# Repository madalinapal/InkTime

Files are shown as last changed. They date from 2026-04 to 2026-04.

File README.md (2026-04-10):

# InkTime Smartwatch

## Overview
InkTime Watch is a low-power smartwatch based on the nRF52840 microcontroller, designed for efficient timekeeping, motion tracking, and e-paper display usage.

## Hardware diagram & features
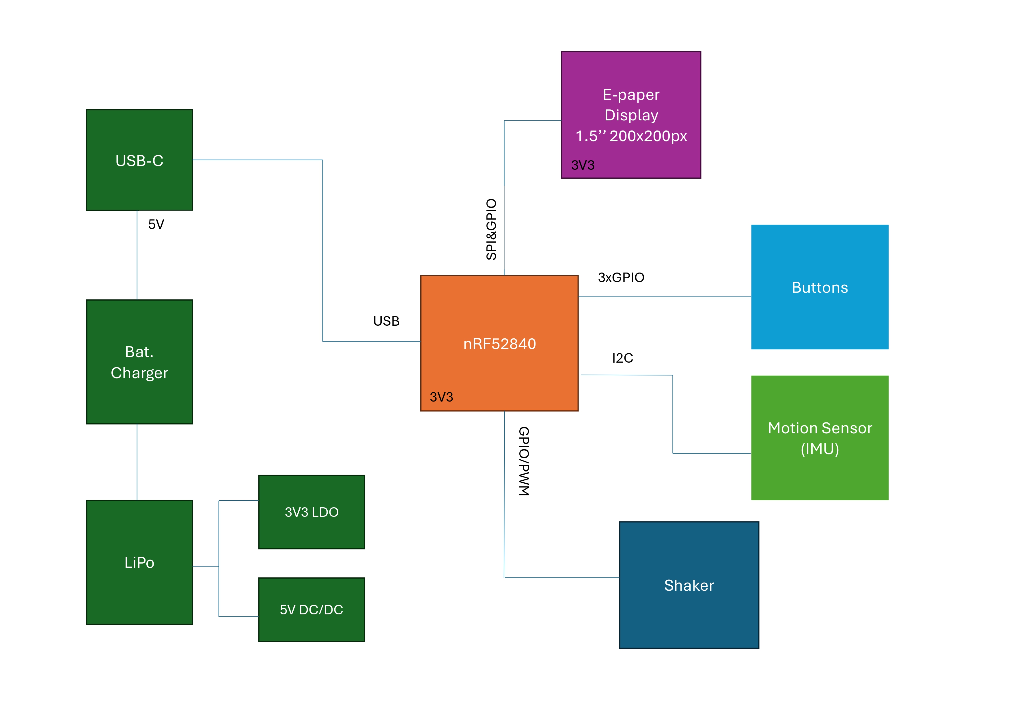
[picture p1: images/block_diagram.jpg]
Block diagram


This is an open-hardware wearable based on the nRF52840 microcontroller. It is fully compatible with embedded C/C++ development and comes with the following features:

* [nRF52840](https://files.seeedstudio.com/wiki/XIAO-BLE/Nano_BLE_MCU-nRF52840_PS_v1.1.pdf) microcontroller (ARM Cortex-M4F @ 64 MHz, Bluetooth 5 / BLE, 2.4 GHz radio, 1 MB Flash and 256 KB RAM, multiple interfaces: SPI, I2C, UART, GPIO, support for external antenna)
* [E-paper Display](https://www.waveshare.com/1.54inch-e-paper-module.htm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) 1.54 inch, 200x200 resolution, communicating via SPI interface
* [BMA423](https://watchy.sqfmi.com/assets/files/BST-BMA423-DS000-1509600-950150f51058597a6234dd3eaafbb1f0.pdf) accelerometer (3-axis ultra-low-power MEMS accelerometer, integrated step counting and activity recognition, motion detection interrupts, FIFO buffer, I2C/SPI interface, optimized for wearable low-power applications)
* [BQ25180](https://www.ti.com/product/BQ25180) LiPo Charger (I2C-controlled single-cell Li-Ion/Li-Po charger, 5V USB input, up to ~250 mA charging current, integrated power path management, ultra-low power for wearables)
* [250 mAh LiPo battery](https://elektronik.ropla.eu/pdf/stock/aky/aky1119.pdf)
* [FIT0774](https://www.tme.eu/ro/details/df-fit0774/motoare-dc/dfrobot/fit0774/) vibration motor (small DC vibration motor, 10 mm diameter, 2.7 mm height, 1.5–4.2 V operating voltage, used for haptic feedback in wearable devices)
* [TC2030-IDC](https://www.digikey.ro/ro/products/detail/tag-connect-llc/TC2030-IDC/4571121) debug connector (Tag-Connect 10-pin SWD programming interface, no-socket pogo-pin connector, supports SWDIO, SWDCLK, RESET, VCC and GND, used for low-profile in-circuit debugging of MCUs)
* [DRV2605L](https://www.ti.com/product/DRV2605L) haptic driver (I2C-controlled vibration motor driver with integrated haptic library, supports ERM and LRA actuators, automatic resonance tuning, low-power operation for wearable haptic feedback systems)
* [DS6160A](https://www.mouser.com/datasheet/2/1458/DS6160A_02-3104604.pdf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) regulator (dual-channel low-power audio power amplifier / driver IC, designed for small speaker or actuator applications, wide supply voltage range, high efficiency Class-D operation, suitable for compact battery-powered systems)
* [MAX17048](https://www.analog.com/en/products/max17048.html) fuel gauge (ultra-low-power single-cell Li-ion battery fuel gauge IC, I2C interface, uses ModelGauge algorithm for accurate state-of-charge estimation, no external sense resistor required, optimized for wearable and portable devices)

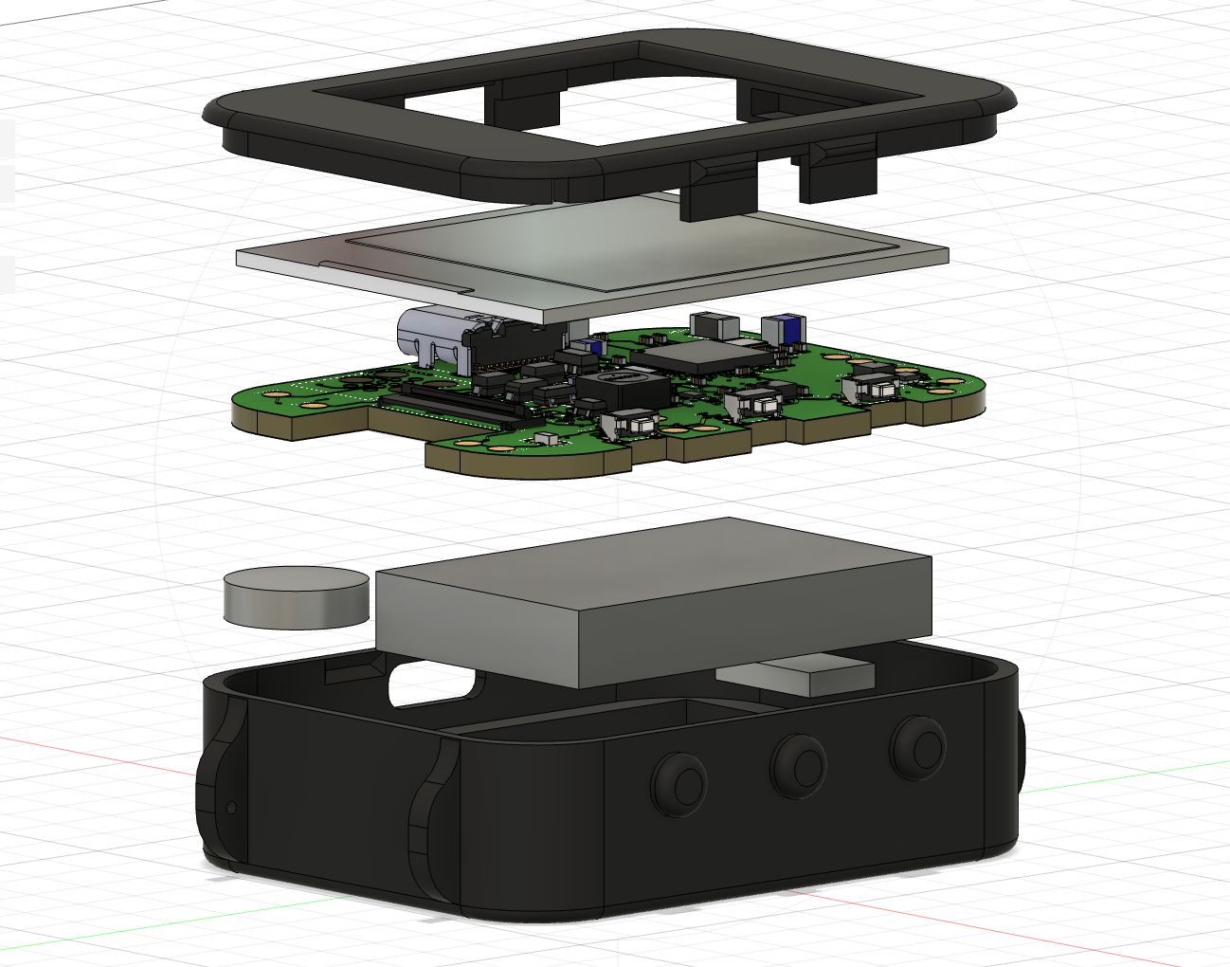
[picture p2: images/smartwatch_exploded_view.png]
Smartwatch exploded view


## Bill of Materials (BOM)

The table below summarizes the main components used in the project. Passive components are grouped by type and package to improve readability.

| Component | Description | Qty | Manufacturer | Part Number | Datasheet | 
|---|---|-----|---|---|---|
| nRF52840 | BLE Microcontroller | 1 | Nordic Semiconductor | nRF52840 | [Datasheet](https://files.seeedstudio.com/wiki/XIAO-BLE/Nano_BLE_MCU-nRF52840_PS_v1.1.pdf) | 
| BMA423 | 3-axis accelerometer (IMU) | 1 | Bosch | BMA423 | [Datasheet](https://watchy.sqfmi.com/assets/files/BST-BMA423-DS000-1509600-950150f51058597a6234dd3eaafbb1f0.pdf) |
| BQ25180 | Battery charger / PMIC | 1 | Texas Instruments | BQ25180 | [Datasheet](https://www.ti.com/product/BQ25180) |
| DRV2605L | Haptic driver | 1 | Texas Instruments | DRV2605L | [Datasheet](https://www.ti.com/product/DRV2605L) |
| MAX17048 | Fuel gauge | 1 | Analog Devices | MAX17048G+T10 | [Datasheet](https://www.analog.com/en/products/max17048.html) | 
| RT6160 | Buck-boost converter | 1 | Richtek | RT6160AWSC | [Datasheet](https://www.mouser.com/datasheet/2/1458/DS6160A_02-3104604.pdf) | 
| 2450AT18B100E | 2.4GHz chip antenna | 1 | Johanson Technology | 2450AT18B100E | [Datasheet](https://jlcpcb.com/api/file/downloadByFileSystemAccessId/8588940948130156544) |
| TC2030-IDC | Programming connector | 1 | Tag-Connect | TC2030-IDC | [Datasheet](https://www.lcsc.com/datasheet/C5444772.pdf) | 
| USB-C Connector | Power & data interface | 1 | Kinghelm | KH-TYPE-C-16P | [Datasheet](https://jlcpcb.com/api/file/downloadByFileSystemAccessId/8588905154556923904) | 
| FPC Connector | E-paper display connector | 1 | Molex | 503480-2400 |[Datasheet](https://www.molex.com/content/dam/molex/molexdotcom/products/automated/enus/salesdrawingpdf/503/503480/5034802400_sd.pdf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)| 
| Push Buttons | Tactile switches | 3 | Panasonic | EVP-AKE31A | [Datasheet](https://wmsc.lcsc.com/wmsc/upload/file/pdf/v2/lcsc/2301111010_PANASONIC-EVPAKE31A_C569760.pdf) | 
| MOSFETs | Power switching | 2 | Vishay / Diodes Inc. | SI1308EDL / DMG2305UX | [Datasheet](https://www.lcsc.com/datasheet/C469327.pdf) | 
| Diodes | Schottky diodes | 3 | ON Semiconductor | MBR0530 | [Datasheet](https://www.lcsc.com/datasheet/C77336.pdf) | 
| ESD Protection | USB protection | 1 | STMicroelectronics | USBLC6-2SC6 | [Datasheet](https://www.lcsc.com/datasheet/C7519.pdf) | 
| Crystal | 32MHz | 1 | NDK | NX2016SA-32MHZ-EXS00A-CS11336 | [Datasheet](https://wmsc.lcsc.com/wmsc/upload/file/pdf/v2/lcsc/2312080231_NDK-NX2016SA-32MHZ-EXS00A-CS11336_C6134317.pdf) | 
| Crystals | 32.768kHz | 1 | Seiko Epson | FC-135 32.7680KA-A3 | [Datasheet](https://jlcpcb.com/partdetail/SeikoEpson-FC_135_32_7680KAA3/C2650472) | 

## nRF52840 Pin Mapping

| Pin nRF52840 | Signal | Component | Interface |
|---|---|---|---|
| P0.00/XL1 | XL1 | Crystal X2 (32.768kHz) | XTAL |
| P0.01/XL2 | XL2 | Crystal X2 (32.768kHz) | XTAL |
| P0.05/AIN3  | EPD_CS | E-Paper (J1 FPC) | SPI CS |
| P0.06 | SDA | BMA423, BQ25180, MAX17048, DRV2605 | I2C SDA |
| P0.07 | SCL | BMA423, BQ25180, MAX17048, DRV2605 | I2C SCL |
| P0.08 | IMU_INT1 | BMA423 | GPIO Input |
| P1.08 | IMU_INT2 | BMA423 | GPIO Input |
| P0.11 | PMIC_INT | BQ25180 | GPIO Input |
| P0.12 | HAPTIC_EN  | DRV2605 | GPIO |
| VBUS | VBUS | USB-C (J4) | Power |
| D- | D- | USB-C (J4) / USBLC6 | USB |
| D+ | D+ | USB-C (J4) / USBLC6 | USB |
| P0.13 | SW_UP | Buton Up | GPIO Input |
| P0.14 | SW_ENT | Buton Enter | GPIO Input |
| P0.15 | EPD_DC | E-Paper (J1 FPC) | SPI DC |
| P0.16 | EPD_RST | E-Paper (J1 FPC) | GPIO |
| P0.17 | EPD_BUSY | E-Paper (J1 FPC) | GPIO Input |
| P0.18/RESET | RESET | TC2030-IDC | SWD/GPIO |
| SWDCLK | SWDCLK | TC2030-IDC | SWD |
| SWDIO | SWDIO | TC2030-IDC | SWD |
| P1.02 | SW_DN | Buton Down | GPIO Input |
| P0.10/NFC2  | ALERT | MAX17048 | GPIO Input |
| ANT | RF | Antena 2450AT18B100E | RF |
| P0.02/AIN0  | SCK | E-Paper (J1 FPC) | SPI SCK |
| P0.03/AIN1  | MOSI | E-Paper (J1 FPC) | SPI MOSI |

## Design Log

This section describes the PCB design process, decisions taken during implementation, and how the project complies with the imposed design constraints.

---

###  Placement Strategy

The layout process started with the placement of mechanically constrained and critical components such as:
- USB-C connector
- Side buttons
- E-paper display connector (FPC)
- nRF52840 microcontroller

These components were positioned according to the mechanical enclosure to ensure proper alignment and usability.

All components were placed exclusively on the **TOP layer**, as required. Passive components (resistors, capacitors) were then distributed around their corresponding ICs, minimizing trace length and ensuring proper decoupling.

Special attention was given to **100nF decoupling capacitors**, which were placed as close as possible to the power pins of each integrated circuit.

---

###  Routing Strategy

Routing was performed on a **4-layer PCB stack-up**, structured as follows:
- Top Layer – signal routing and component placement
- Inner Layer 1 – solid ground plane (GND)
- Inner Layer 2 – power plane (VCC, 3V3, etc.)
- Bottom Layer – signal routing

The routing process followed a hierarchical approach:
- Power traces (VCC, VBUS, 3V3) were routed first
- Signal traces were routed afterwards

Design rules applied:
- Power traces: **≥ 0.3 mm width** 
- Signal traces: **≥ 0.15 mm width**
- No 90° angles were used (only smooth or 45° routing)

The use of internal planes significantly improved power distribution and return paths, reducing noise and ensuring signal integrity.

---

###  Grounding and Planes

A solid grounding strategy was implemented using **polygon pours** on ground layers.

- Ground planes were applied on multiple layers
- **Via stitching** was used extensively to connect ground planes
- Increased via density was applied near the RF section

This improves:
- Signal return paths
- Noise reduction
- EMI performance

---

###  RF and Antenna Considerations

The antenna area was treated as a strict keep-out zone:
- No copper
- No traces
- No vias

---

### Component Constraints

All components respect the required footprint rules:

- Resistors: **0201**
- Capacitors ≤100nF: **0201**
- Capacitors >100nF: **0402**
  
## Design Rule Exceptions (Accepted)

**Trace Width (accepted):**  
Power nets (3V3, VREG, VBAT, VBUS) follow the 0.3 mm rule, but in dense areas around the nRF52840 and tightly packed components, traces are locally reduced due to limited space. These segments are short and were accepted after verification.

**Copper Clearance (accepted):**  
The minimum clearance rule (0.15 mm) is slightly violated in congested regions, especially near the nRF52840 and 0201 components. All cases were manually checked to ensure no shorts.

**Board Edge Clearance (accepted):**  
The USB-C connector (J4) and buttons (SW_UP, SW_DN, SW_ENT) extend beyond the PCB edge for enclosure alignment. This is intentional.

This ensures high-density integration suit

## Repository contens
- schematic.sch → Schematic design file  
- board.brd → PCB layout file  

### Manufacturing
- GerberFiles.zip → PCB manufacturing files (Gerber + drill files)  
- bom.csv / bom.xlsx → Bill of Materials  
- pick&place.cpl → Component placement file 

### Mechanical
- smartwatch_exploded_view.stp → Full 3D exploded view (PCB + battery + display + enclosure)  
- smartwatch.stp → Full 3D view 

### Images
- pcb_2d.png 
- pcb_3d_top_view.png
- pcb_3d_bottom_view.png
- pcb_3d_side_view
- block_diagram.jpg
- smartwatch_final.png
- smartwatch_side_view1.png
- smartwatch_side_view2.png
- smartwatch_exploded_view.png

### License
- LICENSE → Open-source license file 

### Documentation
- README.md → Main project documentation

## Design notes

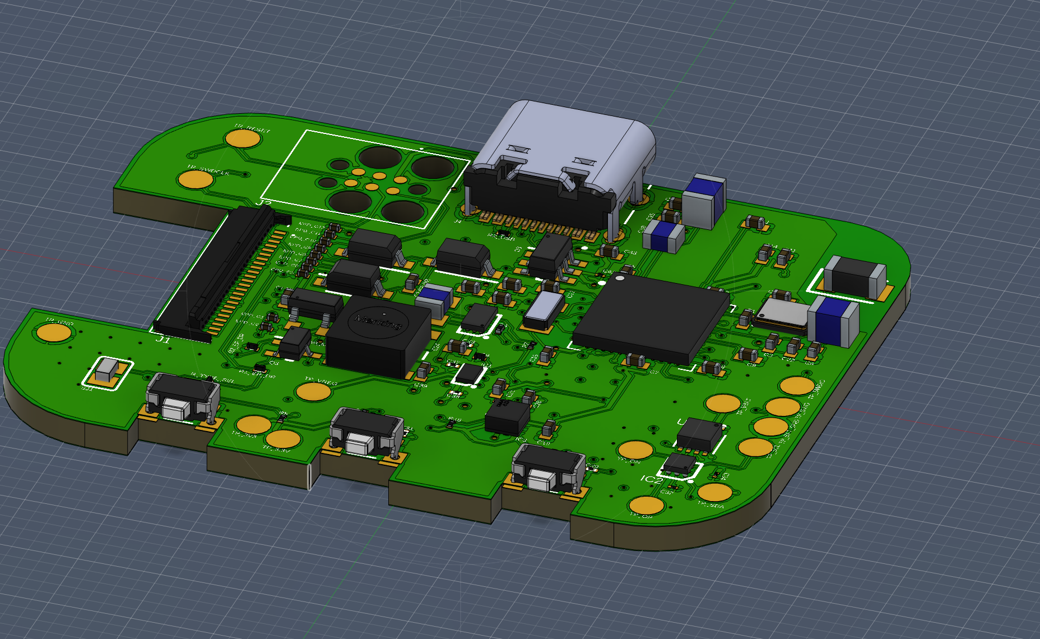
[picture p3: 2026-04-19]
images/pcb_3d_side_view.png

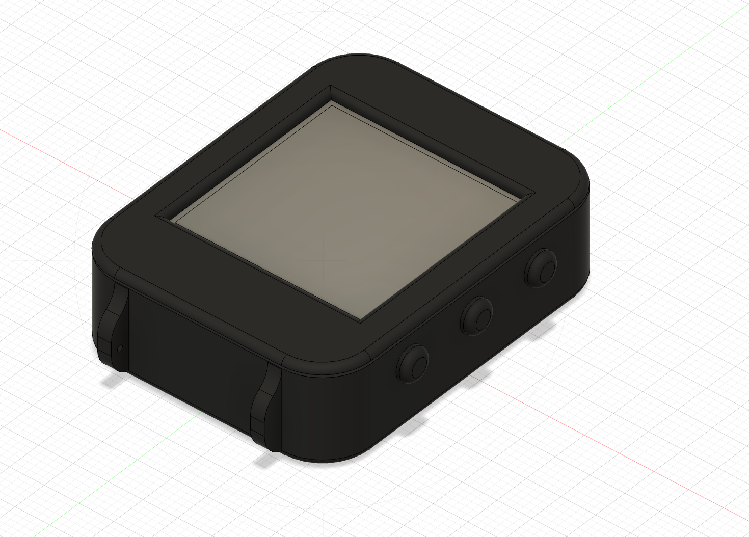
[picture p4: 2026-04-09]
images/smartwatch_final.png

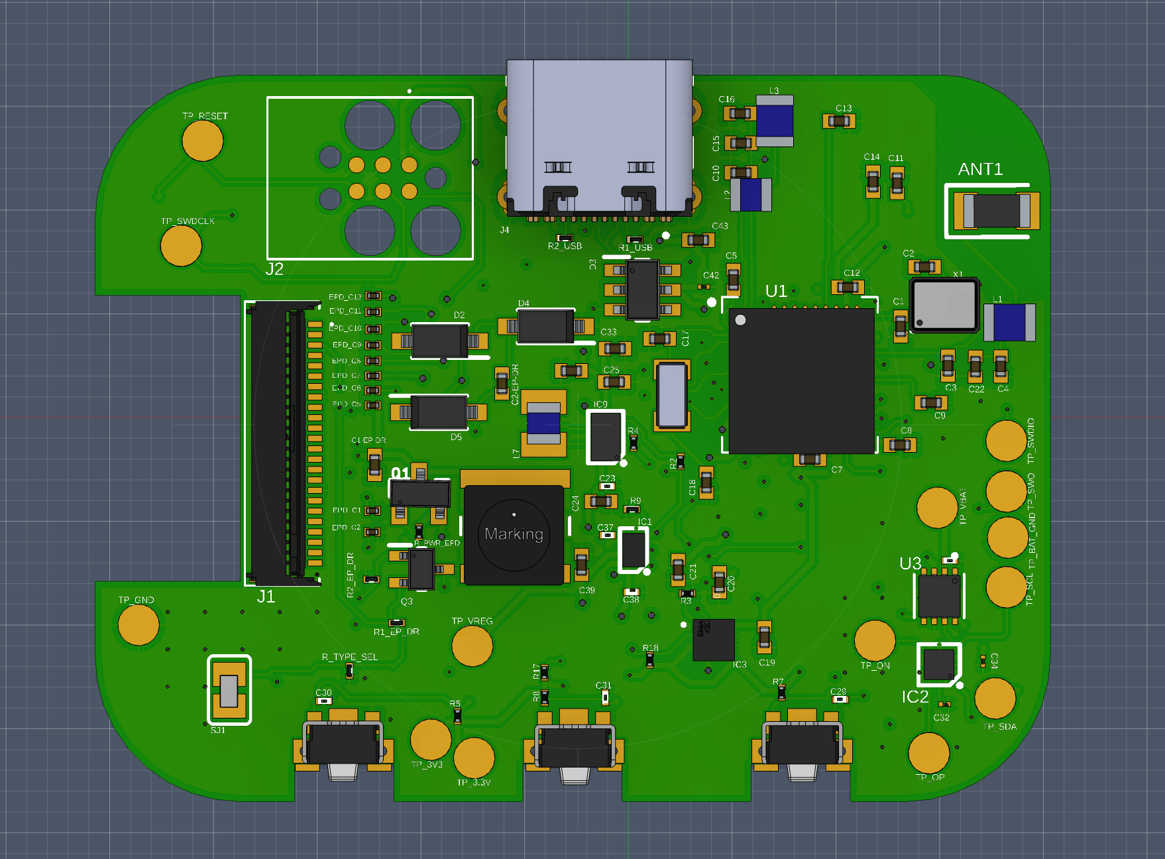
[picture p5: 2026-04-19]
images/pcb_3d_top_view.png

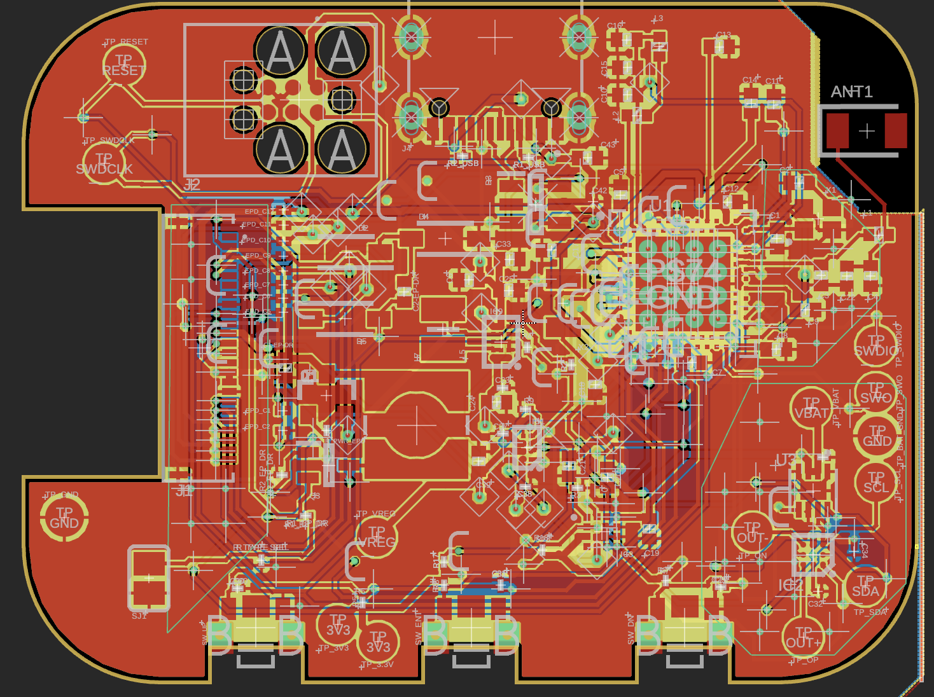
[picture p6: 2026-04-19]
images/pcb_2d.png

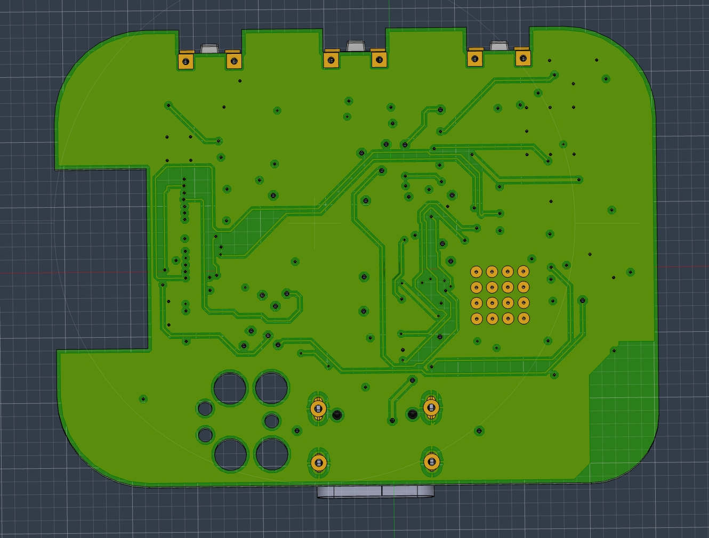
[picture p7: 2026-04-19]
images/pcb_3d_bottom_view.png

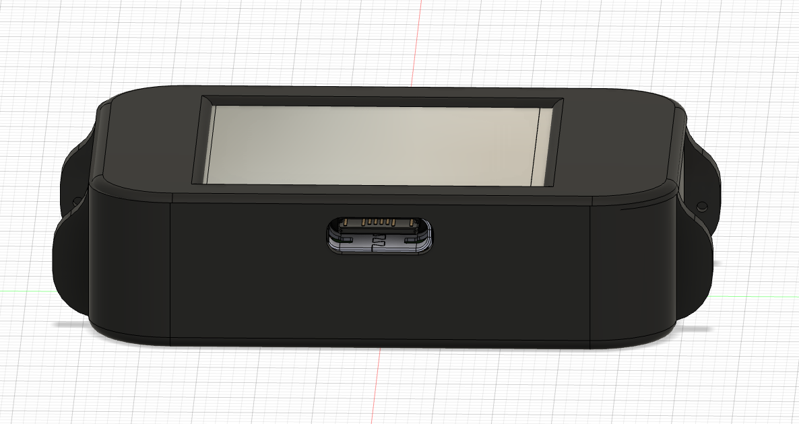
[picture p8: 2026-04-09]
images/smarwatch_side_view1.png

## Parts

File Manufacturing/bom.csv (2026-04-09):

Qty | Value | Device | Package | Parts | Description | ARROW_PART_NUMBER | ARROW_PRICE-STOCK | AVAILABILITY | CHECK_PRICES | COPYRIGHT | DESCRIPTION | DIGI-KEY_PART_NUMBER_1 | DIGI-KEY_PART_NUMBER_2 | DIGI-KEY_PART_NUMBER_3 | HEIGHT | JLCPCB | MANUFACTURER_NAME | MANUFACTURER_PART_NUMBER | MF | MFR_NAME | MOUSER_PART_NUMBER | MOUSER_PRICE-STOCK | MP | PACKAGE | POPULARITY | PRICE | PROD_ID | PURCHASE-URL | SNAPEDA_LINK | TP_SIGNAL_NAME | VALUE
1 |  | 2450AT18B100E_2450AT18B100E | 2450AT18B100E_ANTC3216X140N | ANT1 | Antennas 2.45GHz ANTENNA | 2450AT18B100E | https://www.arrow.com/en/products/2450at18b100e/johanson-dielectrics?utm_currency=USD&region=nac |  |  |  | Antennas 2.45GHz ANTENNA |  |  |  | 1.4mm |  | JOHANSON TECHNOLOGY | 2450AT18B100E |  |  | 609-2450AT18B100E | https://www.mouser.co.uk/ProductDetail/Johanson-Technology/2450AT18B100E?qs=yCnrNFeXz%252Bh5MFsFIXGZGA%3D%3D
1 |  | ESP32_C6_LIBRARY_7_JUMPER_SJ | ESP32_C6_LIBRARY_7_JUMPER_SJ | SJ1 | SMD solder JUMPER |  |  |  |  |  |  |  |  |  |  |  |  |  |  |  |  |  |  |  | 3
3 | 0 | ERA-1AEB3401C_CPF0201D7K68C1 | ERA-1AEB3401C_0201 | R2, R3, R4 | 7.68k 0201 Thin Film Surface Mount Fixed Resistor +/-0.5% 0.031W CPF0201D7K68C1
2 | 0.1uF | GRM011R60J152KE01L_1_GRM011R60J152KE01L | GRM011R60J152KE01L_1_0201 | C23, C27 | Check availability
2 | 0.1uF | GRM011R60J152KE01L_2_GRM011R60J152KE01L | GRM011R60J152KE01L_2_CAPC0201X13N | C34, C42 | Check availability |  |  | In Stock | https://www.snapeda.com/parts/GRM011R60J152KE01L/Murata/view-part/?ref=eda |  | SMD Capacitor X5R(EIA) with Capacitance: 1500pF Tol. 10%. Rated Voltage: 6.3Vdc |  |  |  |  |  |  |  | Murata |  |  |  | GRM011R60J152KE01L | 0201 Murata |  | None |  |  | https://www.snapeda.com/parts/GRM011R60J152KE01L/Murata/view-part/?ref=snap
1 | 0.1uF/50V | NORDIC_NRF_3_CAPACITOR_0201_L | NORDIC_NRF_3_RESC0201_L | EPD_C5 | Generic chip capacitor
1 | 0.47 | CPF0201D7K68C1_CPF0201D7K68C1 | CPF0201D7K68C1_0201 | R1_EP_DR | 7.68k 0201 Thin Film Surface Mount Fixed Resistor +/-0.5% 0.031W CPF0201D7K68C1
1 | 1.0uF | PERFECT_0402_CAP_0402 | PERFECT_0402_0402 | C15 | 0402 (1005 Metric)
5 | 100nF | PERFECT_0402_CAP_0402 | PERFECT_0402_0402 | C5, C7, C8, C12, C19 | 0402 (1005 Metric)
1 | 100pF | PERFECT_0402_CAP_0402 | PERFECT_0402_0402 | C11 | 0402 (1005 Metric)
2 | 10K | CPF0201D7K68C1_CPF0201D7K68C1 | CPF0201D7K68C1_0201 | R2_EP_DR, R9 | 7.68k 0201 Thin Film Surface Mount Fixed Resistor +/-0.5% 0.031W CPF0201D7K68C1
4 | 10K | ERA-1AEB3401C_CPF0201D7K68C1 | ERA-1AEB3401C_0201 | R5, R7, R8, R_PWR_EPD | 7.68k 0201 Thin Film Surface Mount Fixed Resistor +/-0.5% 0.031W CPF0201D7K68C1
3 | 10uF | PERFECT_0402_CAP_0402 | PERFECT_0402_0402 | C1-EP-DR, C24, C39 | 0402 (1005 Metric)
1 | 10uH | NORDIC_NRF_2_INDUCTOR_0402_L | NORDIC_NRF_2_RESC0402_L | L2 | Generic chip inductor
4 | 12pF | PERFECT_0402_CAP_0402 | PERFECT_0402_0402 | C1, C2, C17, C18 | 0402 (1005 Metric)
1 | 15nH | NORDIC_NRF_2_INDUCTOR_0402_L | NORDIC_NRF_2_RESC0402_L | L3 | Generic chip inductor
2 | 1pF | PERFECT_0402_CAP_0402 | PERFECT_0402_0402 | C3, C4 | 0402 (1005 Metric)
5 | 1uF | GRM011R60J152KE01L_1_GRM011R60J152KE01L | GRM011R60J152KE01L_1_0201 | C29, C30, C31, C37, C38 | Check availability
1 | 1uF | GRM011R60J152KE01L_2_GRM011R60J152KE01L | GRM011R60J152KE01L_2_CAPC0201X13N | C32 | Check availability |  |  | In Stock | https://www.snapeda.com/parts/GRM011R60J152KE01L/Murata/view-part/?ref=eda |  | SMD Capacitor X5R(EIA) with Capacitance: 1500pF Tol. 10%. Rated Voltage: 6.3Vdc |  |  |  |  |  |  |  | Murata |  |  |  | GRM011R60J152KE01L | 0201 Murata |  | None |  |  | https://www.snapeda.com/parts/GRM011R60J152KE01L/Murata/view-part/?ref=snap
9 | 1uF/50V | NORDIC_NRF_3_CAPACITOR_0201_L | NORDIC_NRF_3_RESC0201_L | EPD_C1, EPD_C2, EPD_C6, EPD_C7, EPD_C8, EPD_C9, EPD_C10, EPD_C11, EPD_C12 | Generic chip capacitor
1 | 2.2 | CPF0201D7K68C1_CPF0201D7K68C1 | CPF0201D7K68C1_0201 | R_TYPE_SEL | 7.68k 0201 Thin Film Surface Mount Fixed Resistor +/-0.5% 0.031W CPF0201D7K68C1
3 | 2025-10-22_07-23-44_LIBRARY_EVP-AKE31ASW_EVP-AKE31A_PAN | 2025-10-22_07-23-44_LIBRARY_EVP-AKE31ASW_EVP-AKE31A_PAN | 2025-10-22_07-23-44_LIBRARY_SW_EVP-AKE31A_PAN | SW_DN, SW_ENT, SW_UP |  |  |  |  |  | Copyright (C) 2025 Ultra Librarian. All rights reserved. |  | P123437TR-ND | P123437CT-ND | P123437DKR-ND |  |  | Panasonic | EVP-AKE31A
1 | 20V/4.2A/52mΩ/1.4W | ESP32_C6_LIBRARY_4_ESP32_WROVER_SPARKFUN-DISCRETESEMI_MOSFET_PCH-DMG2305UX-7 | ESP32_C6_LIBRARY_4_ESP32_C6_LIBRARY_4_ESP32_C6_LIBRARY_4_ESP32_C6_LIBRARY_4_ESP32_WROVER_SPARKFUN-DISCRETESEMI_SOT23-3 | Q1 | P-channel MOSFETs |  |  |  |  |  |  |  |  |  |  |  |  |  |  |  |  |  |  |  |  |  | TRAN-14388 |  |  |  | 20V/4.2A/52mΩ/1.4W
2 | 22uF | PERFECT_0402_CAP_0402 | PERFECT_0402_0402 | C25, C33 | 0402 (1005 Metric)
1 | 3.9nH | NORDIC_NRF_2_INDUCTOR_0402_L | NORDIC_NRF_2_RESC0402_L | L1 | Generic chip inductor
1 | 32.768kHz | NORDIC_NRF_1_XTAL_32KHZ | NORDIC_NRF_1_XTAL_3215_N | X2
1 | 32MHz | NORDIC_NRF_XTAL_32MHZ | NORDIC_NRF_BT-XTAL_2016_N | X1
2 | 3K3 | ERA-1AEB3401C_CPF0201D7K68C1 | ERA-1AEB3401C_0201 | R17, R18 | 7.68k 0201 Thin Film Surface Mount Fixed Resistor +/-0.5% 0.031W CPF0201D7K68C1
5 | 4.7uF | PERFECT_0402_CAP_0402 | PERFECT_0402_0402 | C6, C14, C20, C21, C43 | 0402 (1005 Metric)
1 | 4.7uF/25V | PERFECT_0402_CAP_0402 | PERFECT_0402_0402 | C2-EP-DR | 0402 (1005 Metric)
1 | 47nF | PERFECT_0402_CAP_0402 | PERFECT_0402_0402 | C16 | 0402 (1005 Metric)
1 | 503480-2400 | 503480-2400_503480-2400 | 503480-2400_5034802400 | J1 | FFC & FPC Connectors 0.5mm FPC RA SMT Dual Contact 24Ckt |  |  |  |  |  | FFC & FPC Connectors 0.5mm FPC RA SMT Dual Contact 24Ckt |  |  |  | 1.87mm |  | Molex | 503480-2400 |  |  | 538-503480-2400 | https://www.mouser.co.uk/ProductDetail/Molex/503480-2400?qs=OAhjpuo3Vu7efIoxFh9AOw%3D%3D
2 | 5K1 | CPF0201D7K68C1_CPF0201D7K68C1 | CPF0201D7K68C1_0201 | R1_USB, R2_USB | 7.68k 0201 Thin Film Surface Mount Fixed Resistor +/-0.5% 0.031W CPF0201D7K68C1
1 | 68uH | ESP32_C6_LIBRARY_2_744043680IND_4828-WE-TPC_WRE | ESP32_C6_LIBRARY_2_IND_4828-WE-TPC_WRE | L5 |  |  |  |  |  | Copyright (C) 2024 Ultra Librarian. All rights reserved. |  |  |  |  |  |  |  | 744043680 |  | Wurth Electronics
1 | 820pF | PERFECT_0402_CAP_0402 | PERFECT_0402_0402 | C9 | 0402 (1005 Metric)
1 | BMA421 | BMA423_BMA423 | BMA423_BMA423 | IC3 | Accelerometers Triaxial low-g 12bit Acceleration Sensor | BMA423 | https://www.arrow.com/en/products/bma423/bosch |  |  |  | Accelerometers Triaxial low-g 12bit Acceleration Sensor |  |  |  | 1mm |  | BOSCH | BMA423 |  |  | 262-BMA423 | https://www.mouser.co.uk/ProductDetail/Bosch-Sensortec/BMA423?qs=HXFqYaX1Q2xC%252BSgeGoX3mg%3D%3D
1 | BQ25180YBGR | BQ25180YBGR_BQ25180YBGR | BQ25180YBGR_BGA8C40P2X4_100X155X50 | IC1 | Charger IC Lithium Ion/Polymer, Lithium Iron Phosphate 8-DSBGA (1.6x1.1) | BQ25180YBGR | https://www.arrow.com/en/products/bq25180ybgr/texas-instruments?utm_currency=USD&region=nac |  |  |  | Charger IC Lithium Ion/Polymer | Lithium Iron Phosphate 8-DSBGA (1.6x1.1) |  |  |  | 0.5mm |  | Texas Instruments | BQ25180YBGR |  |  | 595-BQ25180YBGR | https://www.mouser.co.uk/ProductDetail/Texas-Instruments/BQ25180YBGR?qs=doiCPypUmgEWjAK%252BJAX6Tw%3D%3D
1 | DRV2605YZFR | DRV2605YZFR_DRV2605YZFR | DRV2605YZFR_BGA9C50P3X3_144X144X62 | IC2 | Haptic Driver for ERM/LRA with Built-In Library and Smart Loop Architecture | DRV2605YZFR | https://www.arrow.com/en/products/drv2605yzfr/texas-instruments?region=nac |  |  |  | Haptic Driver for ERM/LRA with Built-In Library and Smart Loop Architecture |  |  |  | 0.625mm |  | Texas Instruments | DRV2605YZFR
1 | FTC252012SR47MBCA | MLP2016SR47MT0S1_FTC252012SR47MBCA | MLP2016SR47MT0S1_INDC2016X100N | L7 | SMD / SMT Inductors (Coils), L=0.47?H, L x W x T : |  |  |  |  |  | SMD / SMT Inductors (Coils) | L=0.47?H | L x W x T : |  |  |  | 1mm | https://jlcpcb.com/partdetail/6763488-FTC252012SR47MBCA/C5832368 | TDK | FTC252012SR47MBCA
14 | HECTOR_WATCH_1_TPTP20R | HECTOR_WATCH_1_TPTP20R | HECTOR_WATCH_1_TP20R | TP_3.3V, TP_3V3, TP_BAT_GND, TP_GND, TP_ON, TP_OP, TP_RESET, TP_SCL, TP_SDA, TP_SWDCLK, TP_SWDIO, TP_SWO, TP_VBAT, TP_VREG | Test pad |  |  |  |  |  |  |  |  |  |  |  |  |  |  |  |  |  |  |  | 2
1 | KH-TYPE-C-16P | KH-TYPE-C-16P_KH-TYPE-C-16P | KH-TYPE-C-16P_KINGHELM_KH-TYPE-C-16P | J4 | Check availability |  |  | Not in stock | https://www.snapeda.com/parts/KH-TYPE-C-16P/Kinghelm/view-part/?ref=eda |  |  |  |  |  |  |  |  |  | kinghelm |  |  |  | KH-TYPE-C-16P | None |  | None |  |  | https://www.snapeda.com/parts/KH-TYPE-C-16P/Kinghelm/view-part/?ref=snap
1 | MAX17048G+T10 | ESP32_C6_LIBRARY_MAX17048G+T10 | ESP32_C6_LIBRARY_SON50P200X200X80-9N | U3 | Check availability |  |  | In Stock | https://www.snapeda.com/parts/MAX17048G+T10/Analog+Devices/view-part/?ref=eda |  | 3µA 1-Cell/2-Cell Fuel Gauge with ModelGauge |  |  |  |  |  |  |  | Analog Devices |  |  |  | MAX17048G+T10 | TDFN-8 Maxim |  | None |  | https://www.snapeda.com/api/url_track_click_mouser/?unipart_id=329239&manufacturer=Analog Devices&part_name=MAX17048G+T10&search_term=None | https://www.snapeda.com/parts/MAX17048G+T10/Analog+Devices/view-part/?ref=snap
3 | MBR0530 | ESP32_C6_LIBRARY_5_MBR0530 | ESP32_C6_LIBRARY_5_SOD3716X135N | D2, D4, D5 | ON SEMICONDUCTOR - MBR0530 - DIODE, SCHOTTKY, 0.5A, 30V, SOD-123 |  |  | In Stock | https://www.snapeda.com/parts/MBR0530/Onsemi/view-part/?ref=eda |  | Diode Schottky 30 V 500mA Surface Mount SOD-123 |  |  |  |  |  |  |  | ON Semiconductor |  |  |  | MBR0530 | SOD-123-2 ON Semiconductor |  | None |  | https://www.snapeda.com/api/url_track_click_mouser/?unipart_id=179458&manufacturer=ON Semiconductor&part_name=MBR0530&search_term=None | https://www.snapeda.com/parts/MBR0530/Onsemi/view-part/?ref=snap
3 | N.C. | PERFECT_0402_CAP_0402 | PERFECT_0402_0402 | C10, C13, C22 | 0402 (1005 Metric)
1 | NRF52840_QF | NORDIC_NRF_4_NRF52840_QF | NORDIC_NRF_4_AQFN50P700X700X85_HS-74N | U1 | nRF52840
1 | RT6160AWSC | RT6160AWSC_RT6160AWSC | RT6160AWSC_BGA15C40P3X5_140X230X60 | IC9 | Buck-Boost Regulator Positive Output Step-Up/Step-Down I2C DC-DC Controller IC 15-WL-CSP (BSC) (1.4x2.3) |  |  |  |  |  | Buck-Boost Regulator Positive Output Step-Up/Step-Down I2C DC-DC Controller IC 15-WL-CSP (BSC) (1.4x2.3) |  |  |  | 0.6mm |  | RICHTEK | RT6160AWSC |  |  | 835-RT6160AWSC | https://www.mouser.co.uk/ProductDetail/Richtek/RT6160AWSC?qs=amGC7iS6iy%2FLd9PSoixZXQ%3D%3D
1 | SI1308EDL-T1-GE3 | ESP32_C6_LIBRARY_6_SI1308EDL-T1-GE3 | ESP32_C6_LIBRARY_6_SOT65P210X110-3N | Q3 | MOSFET N-Ch 30V 1.5A TrenchFET SC70 Vishay Si1308EDL-T1-GE3 N-channel MOSFET Transistor, 1.5 A, 30 V, 3-Pin SC-70 |  |  | In Stock | https://www.snapeda.com/parts/SI1308EDL-T1-GE3/Vishay+Siliconix/view-part/?ref=eda |  | Si1308EDL-T1-GE3 N-channel MOSFET Transistor | 1.5 A | 30 V | 3-Pin SC-70 | Siliconix / Vishay SI1308EDL-T1-GE3 |  |  |  |  |  |  |  | Vishay Siliconix |  |  |  | SI1308EDL-T1-GE3 | SOT-323 Vishay Semiconductor |  | None |  | https://www.snapeda.com/api/url_track_click_mouser/?unipart_id=274603&manufacturer=Vishay Siliconix&part_name=SI1308EDL-T1-GE3&search_term=None
1 | TC2030-IDC | TC2030-IDC_TC2030-IDC | TC2030-IDC_TC2030IDC | J2 | CABLE ADAPTER 6 POS |  |  |  |  |  | CABLE ADAPTER 6 POS |  |  |  | 19mm |  | Tag Connect | TC2030-IDC
1 | USBLC6-2SC6Y | ESP32_C6_LIBRARY_3_USBLC6-2SC6Y | ESP32_C6_LIBRARY_3_SOT95P280X145-6N | D3 | Low Cap. ESD Protection Auto SOT-23-6 STMicroelectronics USBLC6-2SC6Y, Dual Uni-Directional TVS Diode Array, 6-Pin SOT-23 |  |  | In Stock | https://www.snapeda.com/parts/USBLC6-2SC6Y/STMicroelectronics/view-part/?ref=eda |  | 17V Clamp 5A (8/20µs) Ipp Tvs Diode Surface Mount SOT-23-6 |  |  |  |  |  |  |  | STMicroelectronics |  |  |  | USBLC6-2SC6Y | SOT-23-6 STMicroelectronics |  | None |  |  | https://www.snapeda.com/parts/USBLC6-2SC6Y/STMicroelectronics/view-part/?ref=snap

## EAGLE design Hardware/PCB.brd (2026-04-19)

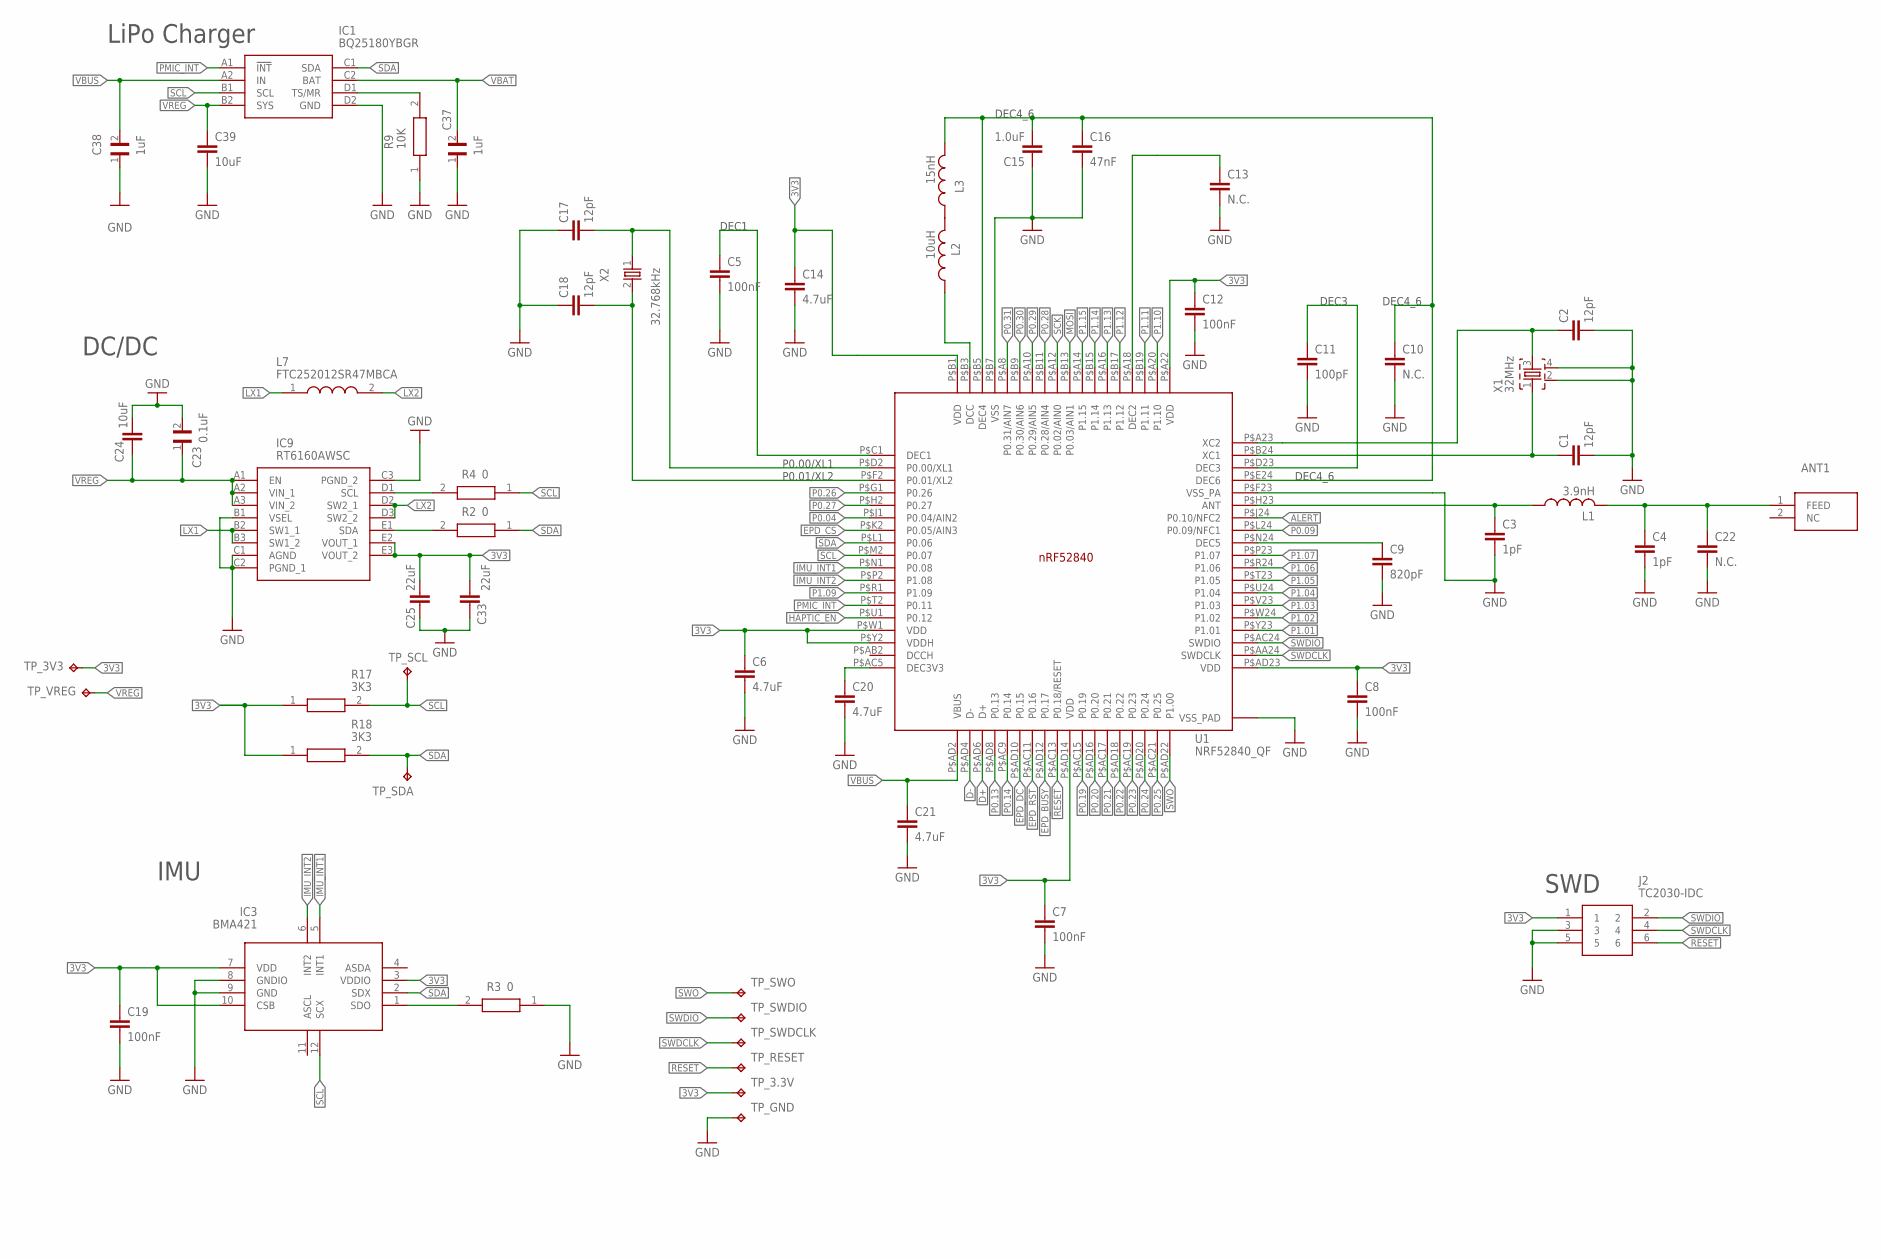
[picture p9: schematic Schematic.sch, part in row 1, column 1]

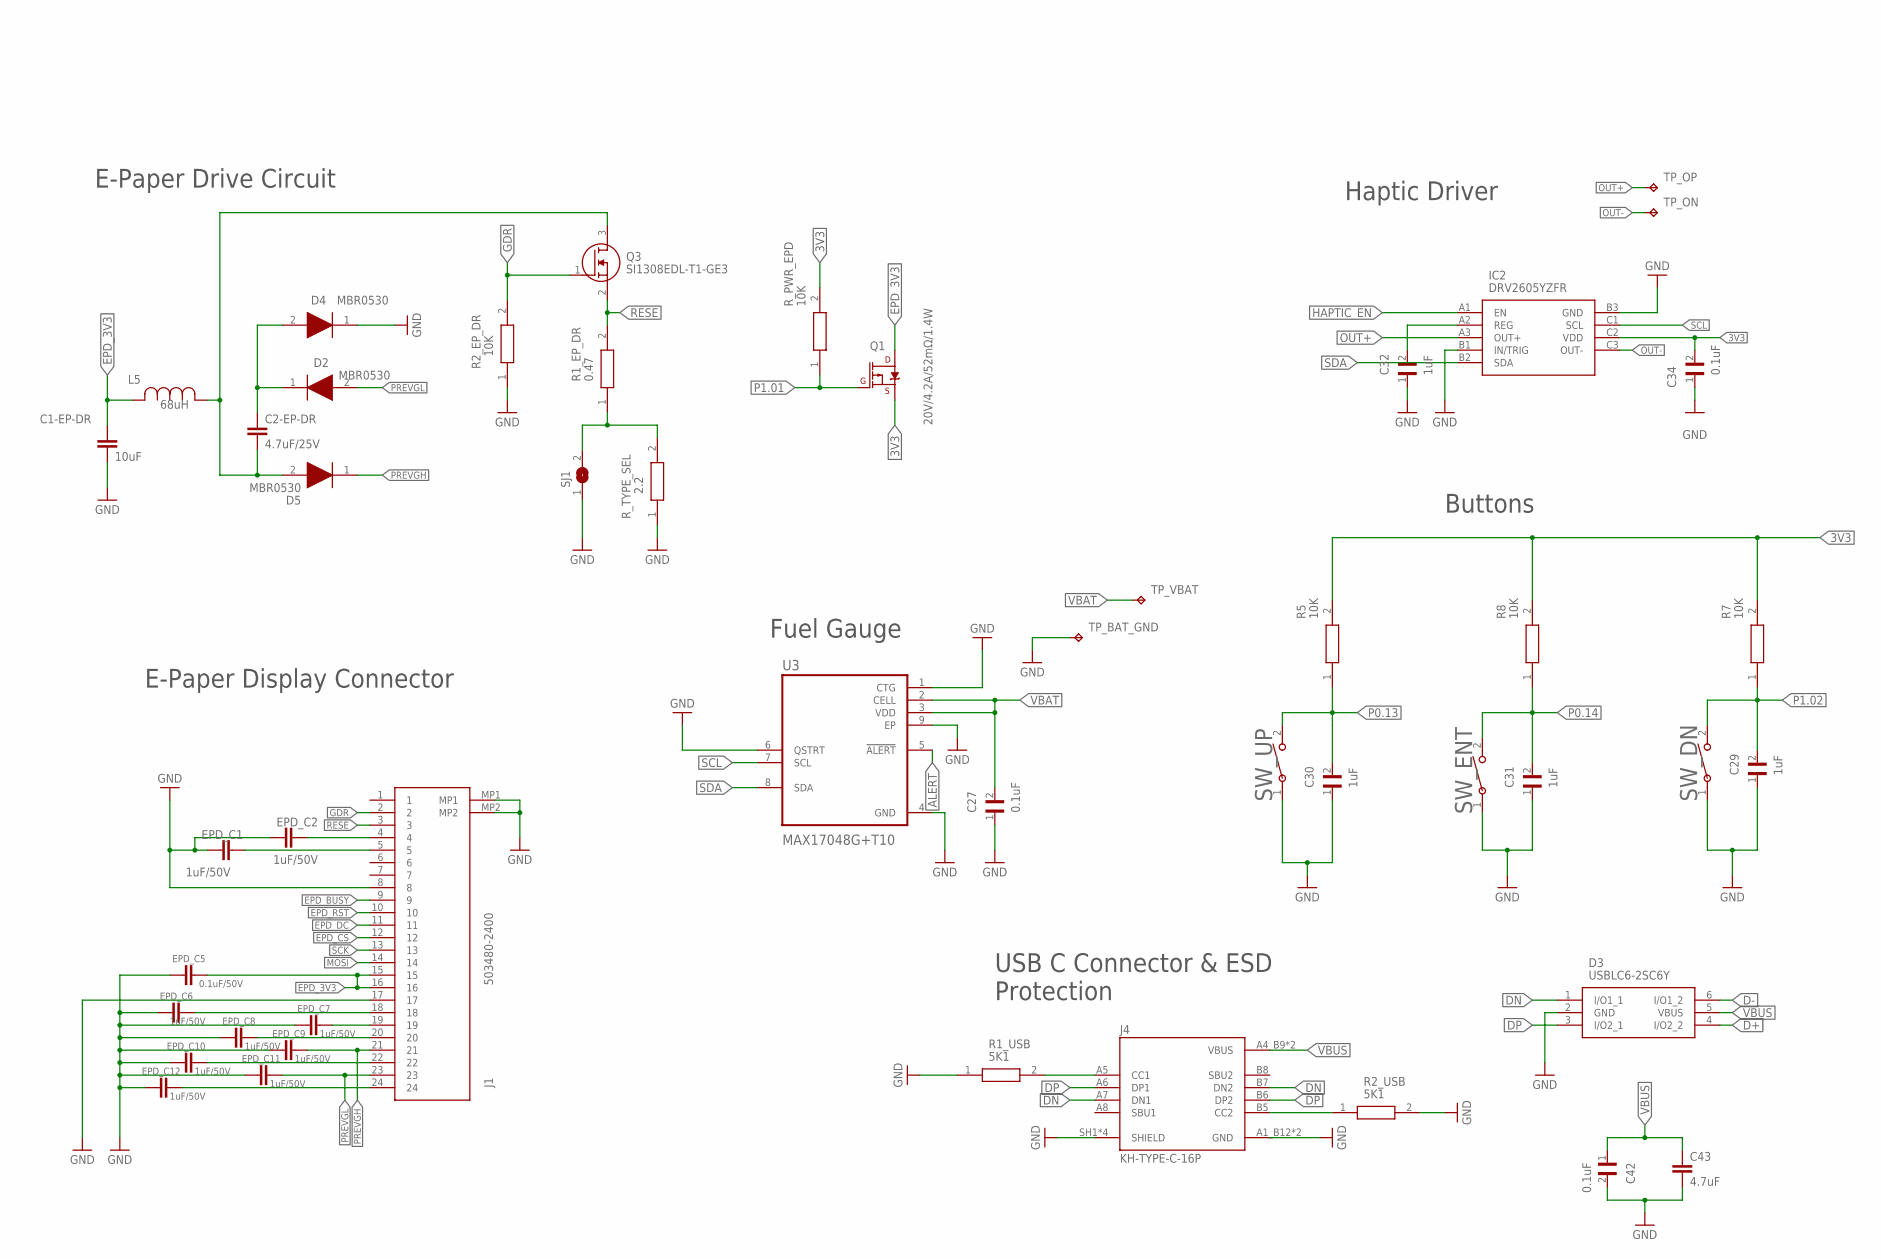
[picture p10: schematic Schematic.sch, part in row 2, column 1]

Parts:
ANT1: 2450AT18B100E_2450AT18B100E; 2450AT18B100E_ANTC3216X140N
C1, C2, C17, C18: 12pF; PERFECT_0402_0402
C1-EP-DR, C24, C39: 10uF; PERFECT_0402_0402
C2-EP-DR: 4.7uF/25V; PERFECT_0402_0402
C3, C4: 1pF; PERFECT_0402_0402
C5, C7, C8, C12, C19: 100nF; PERFECT_0402_0402
C6, C14, C20, C21, C43: 4.7uF; PERFECT_0402_0402
C9: 820pF; PERFECT_0402_0402
C10, C13, C22: N.C.; PERFECT_0402_0402
C11: 100pF; PERFECT_0402_0402
C15: 1.0uF; PERFECT_0402_0402
C16: 47nF; PERFECT_0402_0402
C23, C27: 0.1uF; GRM011R60J152KE01L_1_0201
C25, C33: 22uF; PERFECT_0402_0402
C29, C30, C31, C37, C38: 1uF; GRM011R60J152KE01L_1_0201
C32: 1uF; GRM011R60J152KE01L_2_CAPC0201X13N
C34, C42: 0.1uF; GRM011R60J152KE01L_2_CAPC0201X13N
D2, D4, D5: MBR0530; ESP32_C6_LIBRARY_5_SOD3716X135N
D3: USBLC6-2SC6Y; ESP32_C6_LIBRARY_3_SOT95P280X145-6N
EPD_C1, EPD_C2, EPD_C6, EPD_C7, EPD_C8, EPD_C9, EPD_C10, EPD_C11, EPD_C12: 1uF/50V; NORDIC_NRF_3_RESC0201_L
EPD_C5: 0.1uF/50V; NORDIC_NRF_3_RESC0201_L
IC1: BQ25180YBGR; BQ25180YBGR_BGA8C40P2X4_100X155X50
IC2: DRV2605YZFR; DRV2605YZFR_BGA9C50P3X3_144X144X62
IC3: BMA421; BMA423_BMA423
IC9: RT6160AWSC; RT6160AWSC_BGA15C40P3X5_140X230X60
J1: 503480-2400; 503480-2400_5034802400
J2: TC2030-IDC; TC2030-IDC_TC2030IDC
J4: KH-TYPE-C-16P; KH-TYPE-C-16P_KINGHELM_KH-TYPE-C-16P
L1: 3.9nH; NORDIC_NRF_2_RESC0402_L
L2: 10uH; NORDIC_NRF_2_RESC0402_L
L3: 15nH; NORDIC_NRF_2_RESC0402_L
L5: 68uH; ESP32_C6_LIBRARY_2_IND_4828-WE-TPC_WRE
L7: FTC252012SR47MBCA; MLP2016SR47MT0S1_INDC2016X100N
Q1: 20V/4.2A/52mΩ/1.4W; ESP32_C6_LIBRARY_4_ESP32_C6_LIBRARY_4_ESP32_C6_LIBRARY_4_ES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
Q3: SI1308EDL-T1-GE3; ESP32_C6_LIBRARY_6_SOT65P210X110-3N
R1_EP_DR: 0.47; CPF0201D7K68C1_0201
R1_USB, R2_USB: 5K1; CPF0201D7K68C1_0201
R2, R3, R4: 0; ERA-1AEB3401C_0201
R2_EP_DR, R9: 10K; CPF0201D7K68C1_0201
R5, R7, R8: 10K; ERA-1AEB3401C_0201
R17, R18: 3K3; ERA-1AEB3401C_0201
R_PWR_EPD: 10K; ERA-1AEB3401C_0201
R_TYPE_SEL: 2.2; CPF0201D7K68C1_0201
SJ1: ESP32_C6_LIBRARY_7_JUMPER_SJ
SW_DN: 2025-10-22_07-23-44_LIBRARY_EVP-AKE31ASW_EVP-AKE3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; 2025-10-22_07-23-44_LIBRARY_SW_EVP-AKE31A_PAN
SW_ENT: 2025-10-22_07-23-44_LIBRARY_EVP-AKE31ASW_EVP-AKE3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; 2025-10-22_07-23-44_LIBRARY_SW_EVP-AKE31A_PAN
SW_UP: 2025-10-22_07-23-44_LIBRARY_EVP-AKE31ASW_EVP-AKE3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; 2025-10-22_07-23-44_LIBRARY_SW_EVP-AKE31A_PAN
TP_3.3V, TP_3V3: HECTOR_WATCH_1_TPTP20R; HECTOR_WATCH_1_TP20R
TP_BAT_GND: HECTOR_WATCH_1_TPTP20R; HECTOR_WATCH_1_TP20R
TP_GND: HECTOR_WATCH_1_TPTP20R; HECTOR_WATCH_1_TP20R
TP_ON: HECTOR_WATCH_1_TPTP20R; HECTOR_WATCH_1_TP20R
TP_OP: HECTOR_WATCH_1_TPTP20R; HECTOR_WATCH_1_TP20R
TP_RESET: HECTOR_WATCH_1_TPTP20R; HECTOR_WATCH_1_TP20R
TP_SCL: HECTOR_WATCH_1_TPTP20R; HECTOR_WATCH_1_TP20R
TP_SDA: HECTOR_WATCH_1_TPTP20R; HECTOR_WATCH_1_TP20R
TP_SWDCLK: HECTOR_WATCH_1_TPTP20R; HECTOR_WATCH_1_TP20R
TP_SWDIO: HECTOR_WATCH_1_TPTP20R; HECTOR_WATCH_1_TP20R
TP_SWO: HECTOR_WATCH_1_TPTP20R; HECTOR_WATCH_1_TP20R
TP_VBAT: HECTOR_WATCH_1_TPTP20R; HECTOR_WATCH_1_TP20R
TP_VREG: HECTOR_WATCH_1_TPTP20R; HECTOR_WATCH_1_TP20R
U1: NRF52840_QF; NORDIC_NRF_4_AQFN50P700X700X85_HS-74N
U3: MAX17048G+T10; ESP32_C6_LIBRARY_SON50P200X200X80-9N
X1: 32MHz; NORDIC_NRF_BT-XTAL_2016_N
X2: 32.768kHz; NORDIC_NRF_1_XTAL_3215_N

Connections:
3V3: C6.1, C7.1, C8.1, C12.1, C14.1, C19.1, C25.1, C33.1, C34.2, IC2.C2 (VDD), IC3.3 (VDDIO), IC3.7 (VDD), IC3.10 (CSB), IC9.E2 (VOUT_1), IC9.E3 (VOUT_2), J2.1, Q1.2 (S), R5.2, R7.2, R8.2, R17.1, R18.1, R_PWR_EPD.2, TP_3.3V.TP, TP_3V3.TP, U1.P$A22 (VDD), U1.P$AD14 (VDD), U1.P$AD23 (VDD), U1.P$B1 (VDD), U1.P$W1 (VDD), U1.P$Y2 (VDDH)
ALERT: U1.P$J24 (P0.10/NFC2), U3.5 (!ALERT)
D+: D3.4 (I/O2_2), U1.P$AD6 (D+)
D-: D3.6 (I/O1_2), U1.P$AD4 (D-)
DN: D3.1 (I/O1_1), J4.A7 (DN1), J4.B7 (DN2)
DP: D3.3 (I/O2_1), J4.A6 (DP1), J4.B6 (DP2)
EPD_3V3: C1-EP-DR.1, EPD_C5.2, J1.15, J1.16, L5.2, Q1.3 (D)
EPD_BUSY: J1.9, U1.P$AD12 (P0.17)
EPD_CS: J1.12, U1.P$K2 (P0.05/AIN3)
EPD_DC: J1.11, U1.P$AD10 (P0.15)
EPD_RST: J1.10, U1.P$AC11 (P0.16)
GDR: J1.2, Q3.1 (G), R2_EP_DR.2
GND: C1.2, C1-EP-DR.2, C2.2, C3.2, C4.2, C5.2, C6.2, C7.2, C8.2, C9.2, C10.2, C11.2, C12.2, C13.2, C14.2, C15.1, C16.2, C17.1, C18.1, C19.2, C20.2, C21.2, C22.2, C23.2, C24.1, C25.2, C27.1, C29.1, C30.1, C31.1, C32.1, C33.2, C34.1, C37.1, C38.1, C39.2, C42.2, C43.2, D3.2 (GND), D4.1 (K), EPD_C1.1, EPD_C2.1, EPD_C5.1, EPD_C6.1, EPD_C7.1, EPD_C8.1, EPD_C9.1, EPD_C10.1, EPD_C11.1, EPD_C12.1, IC1.D2 (GND), IC2.B1 (IN/TRIG), IC2.B3 (GND), IC3.8 (GNDIO), IC3.9 (GND), IC9.B1 (VSEL), IC9.C1 (AGND), IC9.C2 (PGND_1), IC9.C3 (PGND_2), J1.8, J1.17, J1.MP1, J1.MP2, J2.3, J2.5, J4.A1_B12 (GND), J4.A12_B1 (GND), J4.SH1 (SHIELD), J4.SH2 (SHIELD), J4.SH3 (SHIELD), J4.SH4 (SHIELD), R1_USB.1, R2_EP_DR.1, R2_USB.2, R3.1, R9.1, R_TYPE_SEL.1, SJ1.1, SW_DN.1, SW_ENT.1, SW_UP.1, TP_BAT_GND.TP, TP_GND.TP, U1.P$74 (VSS_PAD), U1.P$75 (VSS_PAD), U1.P$76 (VSS_PAD), U1.P$77 (VSS_PAD), U1.P$78 (VSS_PAD), U1.P$79 (VSS_PAD), U1.P$80 (VSS_PAD), U1.P$81 (VSS_PAD), U1.P$82 (VSS_PAD), U1.P$83 (VSS_PAD), U1.P$84 (VSS_PAD), U1.P$85 (VSS_PAD), U1.P$86 (VSS_PAD), U1.P$87 (VSS_PAD), U1.P$88 (VSS_PAD), U1.P$89 (VSS_PAD), U1.P$90 (VSS_PAD), U1.P$B7 (VSS), U1.P$F23 (VSS_PA), U3.1 (CTG), U3.4 (GND), U3.6 (QSTRT), U3.9 (EP), X1.2, X1.4
HAPTIC_EN: IC2.A1 (EN), U1.P$U1 (P0.12)
IMU_INT1: IC3.5 (INT1), U1.P$N1 (P0.08)
IMU_INT2: IC3.6 (INT2), U1.P$P2 (P1.08)
LX1: IC9.B2 (SW1_1), IC9.B3 (SW1_2), L7.1
LX2: IC9.D2 (SW2_1), IC9.D3 (SW2_2), L7.2
MOSI: J1.14, U1.P$B13 (P0.03/AIN1)
unnamed: IC1.D1 (TS/MR), R9.2
unnamed: IC9.D1 (SCL), R4.2
unnamed: IC9.E1 (SDA), R2.2
unnamed: IC3.1 (SDO), R3.2
unnamed: C20.1, U1.P$AC5 (DEC3V3)
unnamed: C9.1, U1.P$N24 (DEC5)
unnamed: ANT1.1 (FEED), C4.1, C22.1, L1.2
unnamed: C3.1, L1.1, U1.P$H23 (ANT)
unnamed: C2.1, U1.P$A23 (XC2), X1.3
unnamed: C1.1, U1.P$B24 (XC1), X1.1
unnamed: C5.1, U1.P$C1 (DEC1)
unnamed: C18.2, U1.P$F2 (P0.01/XL2), X2.2
unnamed: C17.2, U1.P$D2 (P0.00/XL1), X2.1
unnamed: C11.1, U1.P$D23 (DEC3)
unnamed: C2-EP-DR.2, D5.2 (A), L5.1, Q3.3 (D)
unnamed: C13.1, U1.P$A18 (DEC2)
unnamed: L2.2, L3.1
unnamed: L2.1, U1.P$B3 (DCC)
unnamed: C10.1, C15.2, C16.1, L3.2, U1.P$B5 (DEC4), U1.P$E24 (DEC6)
unnamed: C2-EP-DR.1, D2.1 (K), D4.2 (A)
unnamed: EPD_C2.2, J1.4
unnamed: R1_EP_DR.1, R_TYPE_SEL.2, SJ1.2
unnamed: EPD_C1.2, J1.5
unnamed: C32.2, IC2.A2 (REG)
unnamed: EPD_C6.2, J1.18
unnamed: EPD_C7.2, J1.19
unnamed: J4.A5 (CC1), R1_USB.2
unnamed: J4.B5 (CC2), R2_USB.1
unnamed: EPD_C8.2, J1.20
unnamed: EPD_C10.2, J1.22
unnamed: EPD_C12.2, J1.24
OUT+: IC2.A3 (OUT+), TP_OP.TP
OUT-: IC2.C3 (OUT-), TP_ON.TP
P0.04: U1.P$J1 (P0.04/AIN2)
P0.09: U1.P$L24 (P0.09/NFC1)
P0.13: C30.2, R5.1, SW_UP.2, U1.P$AD8 (P0.13)
P0.14: C31.2, R8.1, SW_ENT.2, U1.P$AC9 (P0.14)
P0.19: U1.P$AC15 (P0.19)
P0.20: U1.P$AD16 (P0.20)
P0.21: U1.P$AC17 (P0.21)
P0.22: U1.P$AD18 (P0.22)
P0.23: U1.P$AC19 (P0.23)
P0.24: U1.P$AD20 (P0.24)
P0.25: U1.P$AC21 (P0.25)
P0.26: U1.P$G1 (P0.26)
P0.27: U1.P$H2 (P0.27)
P0.28: U1.P$B11 (P0.28/AIN4)
P0.29: U1.P$A10 (P0.29/AIN5)
P0.30: U1.P$B9 (P0.30/AIN6)
P0.31: U1.P$A8 (P0.31/AIN7)
P1.01: Q1.1 (G), R_PWR_EPD.1, U1.P$Y23 (P1.01)
P1.02: C29.2, R7.1, SW_DN.2, U1.P$W24 (P1.02)
P1.03: U1.P$V23 (P1.03)
P1.04: U1.P$U24 (P1.04)
P1.05: U1.P$T23 (P1.05)
P1.06: U1.P$R24 (P1.06)
P1.07: U1.P$P23 (P1.07)
P1.09: U1.P$R1 (P1.09)
P1.10: U1.P$A20 (P1.10)
P1.11: U1.P$B19 (P1.11)
P1.12: U1.P$B17 (P1.12)
P1.13: U1.P$A16 (P1.13)
P1.14: U1.P$B15 (P1.14)
P1.15: U1.P$A14 (P1.15)
PMIC_INT: IC1.A1 (!INT), U1.P$T2 (P0.11)
PREVGH: D5.1 (K), EPD_C9.2, J1.21
PREVGL: D2.2 (A), EPD_C11.2, J1.23
RESE: J1.3, Q3.2 (S), R1_EP_DR.2
RESET: J2.6, TP_RESET.TP, U1.P$AC13 (P0.18/RESET)
SCK: J1.13, U1.P$A12 (P0.02/AIN0)
SCL: IC1.B1 (SCL), IC2.C1 (SCL), IC3.12 (SCX), R4.1, R17.2, TP_SCL.TP, U1.P$M2 (P0.07), U3.7 (SCL)
SDA: IC1.C1 (SDA), IC2.B2 (SDA), IC3.2 (SDX), R2.1, R18.2, TP_SDA.TP, U1.P$L1 (P0.06), U3.8 (SDA)
SWDCLK: J2.4, TP_SWDCLK.TP, U1.P$AA24 (SWDCLK)
SWDIO: J2.2, TP_SWDIO.TP, U1.P$AC24 (SWDIO)
SWO: TP_SWO.TP, U1.P$AD22 (P1.00)
VBAT: C27.2, C37.2, IC1.C2 (BAT), TP_VBAT.TP, U3.2 (CELL), U3.3 (VDD)
VBUS: C21.1, C38.2, C42.1, C43.1, D3.5 (VBUS), IC1.A2 (IN), J4.A4_B9 (VBUS), J4.A9_B4 (VBUS), U1.P$AD2 (VBUS)
VREG: C23.1, C24.2, C39.1, IC1.B2 (SYS), IC9.A1 (EN), IC9.A2 (VIN_1), IC9.A3 (VIN_2), TP_VREG.TP

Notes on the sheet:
LiPo Charger
DC/DC
IMU
DEC4_6
DEC3
DEC1
P0.00/XL1
P0.01/XL2
SWD
E-Paper Drive Circuit
Haptic Driver
Buttons
Fuel Gauge
USB C Connector & ESD Protection
E-Paper Display Connector

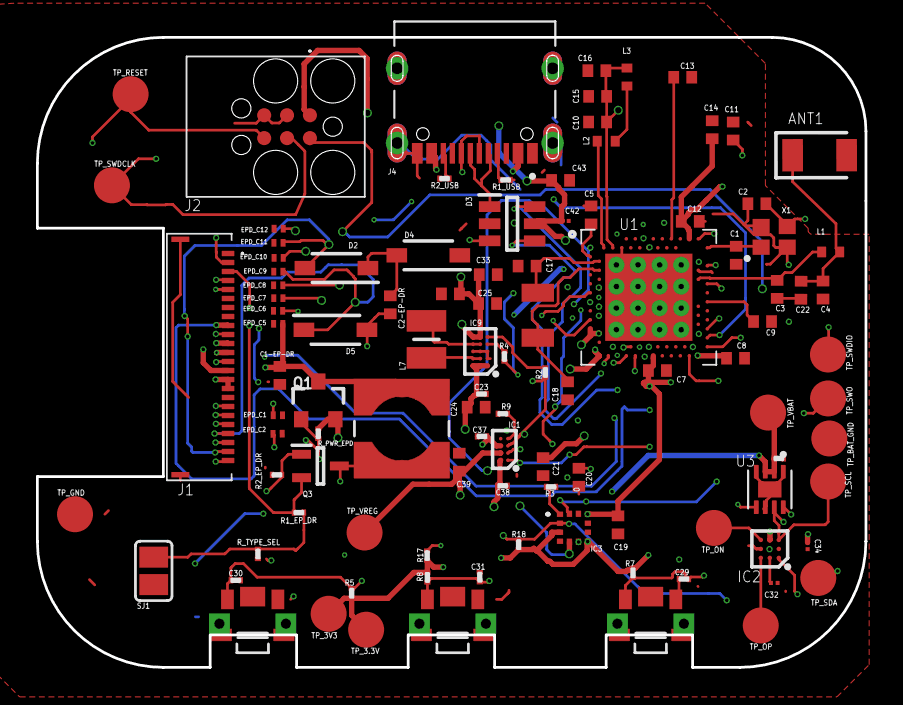
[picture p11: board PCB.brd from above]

Board: 2 copper layers, 46.0 x 35.0 mm, 105 parts (0 on the bottom side), 70 nets.

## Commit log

2026-04-09 Update README with nRF52840 pin mapping and contents
    Added detailed pin mapping for nRF52840 and repository contents.
2026-04-10 Fix BOM table formatting and update links
2026-04-10 updated pcb
    [PCB.brd]
2026-04-10 Update README with design rule exceptions
    Added design rule exceptions for trace width, copper clearance, and board edge clearance.
2026-04-19 solved issue
    [PCB.brd]

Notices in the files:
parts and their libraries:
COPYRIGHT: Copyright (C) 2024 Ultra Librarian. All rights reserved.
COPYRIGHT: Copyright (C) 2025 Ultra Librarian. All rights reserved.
